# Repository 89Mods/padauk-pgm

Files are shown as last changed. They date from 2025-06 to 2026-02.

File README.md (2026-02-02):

# PMS150 programmer

Open-source programmer for the Padauk PMS150 / PMC150 devices, specifically the SOT23-5 variants (SOIC-8 not supported right now).

This programmer was designed to replicate the scope traces from reverse engineering of the official programmer as closely as possible. The only thing it can’t do is modulate the VDD voltage on the target device, but can change the VPP voltage to any level between 7V and 13V or shut it off entirely.

This project is not yet the simplest possible programmer, just a jumping off point for me to start optimizing from. Its actually quite overkill, as experimenting with the hardware already shows that a constant VPP of 11V is fine and, except for Q3, the FETs could be replaced by direct connections to GPIO pins on the CH32V003. The currents involved are way too tiny to require FETs to switch them. At some point in the future, I will make a new revision of this programmer that is truly as minimal as possible.

Included in this repo is also a primitive Verilog model of this MCU, together with a verilator testbench to help me test my code before I burn it onto a OTP device.

I also added support for PDK13 devices to my fork of the AS Assembler. [Check it out here.](https://github.com/AvalonSemiconductors/asl-avalonsemi/tree/avalonsemi)

The SPI programming interface does not reset properly unless ALL chip pins are floated! I believed that having the SPI lines and GND pin connected to ground while power is reset would be alright, but this breaks things. All must be floated.

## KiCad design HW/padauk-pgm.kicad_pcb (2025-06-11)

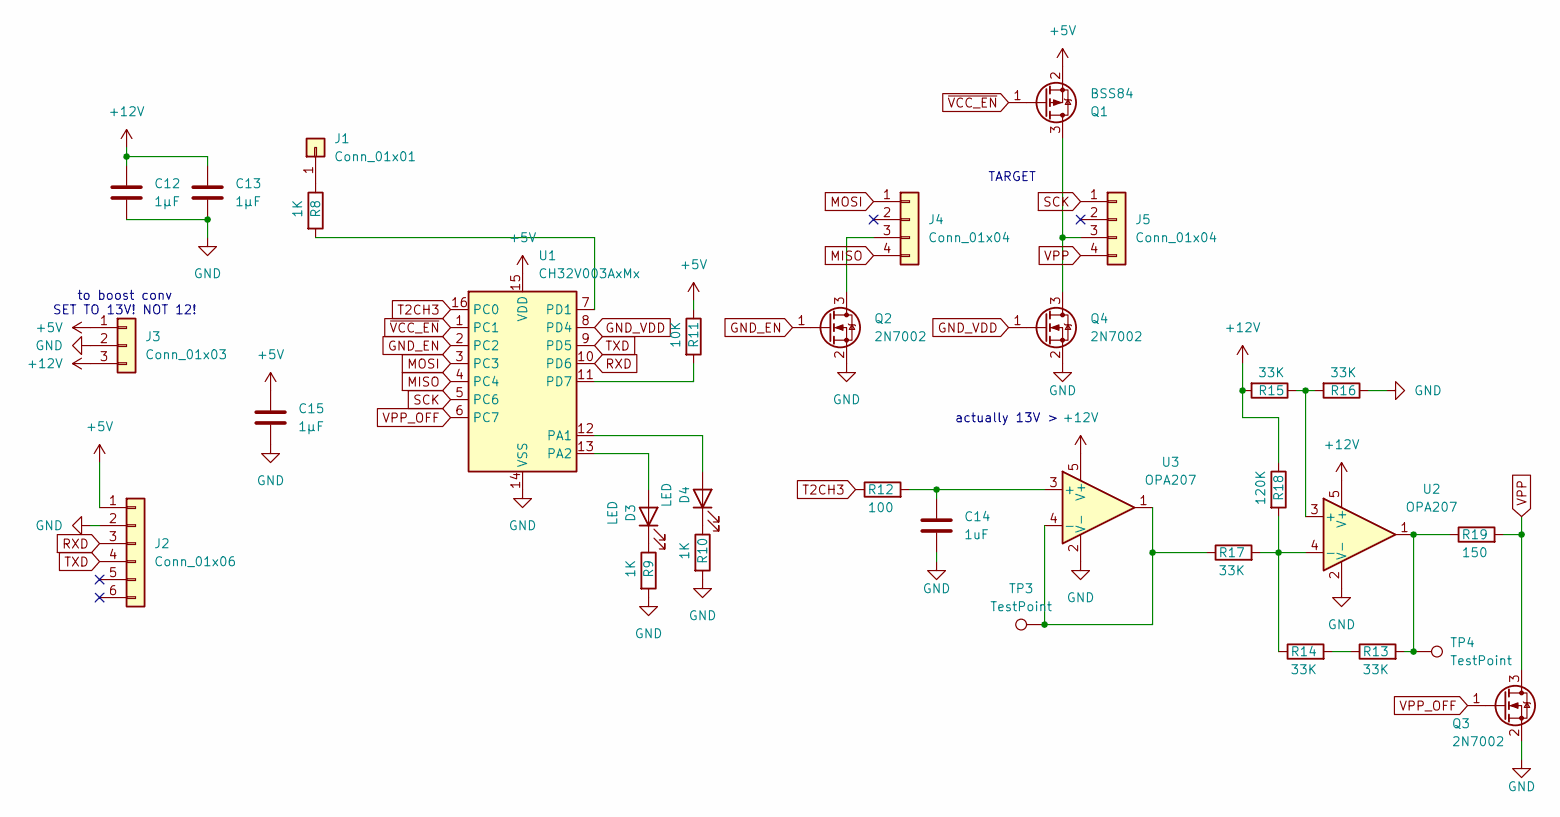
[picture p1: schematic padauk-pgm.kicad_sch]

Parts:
C12, C13, C15: 1µF; C_0805_2012Metric_Pad1.18x1.45mm_HandSolder
C14: 1uF; C_1206_3216Metric
D3, D4: LED; LED_1206_3216Metric_Pad1.42x1.75mm_HandSolder
J1: Conn_01x01; PinHeader_1x01_P2.54mm_Vertical
J2: Conn_01x06; PinSocket_1x06_P2.54mm_Vertical
J3: Conn_01x03; PinHeader_1x03_P2.54mm_Vertical
J4, J5: Conn_01x04; PinHeader_1x04_P2.54mm_Vertical
Q1: BSS84; SOT-23
Q2, Q3, Q4: 2N7002; SOT-23
R8, R9, R10: 1K; R_1206_3216Metric_Pad1.30x1.75mm_HandSolder
R11: 10K; R_1206_3216Metric_Pad1.30x1.75mm_HandSolder
R12: 100; R_1206_3216Metric_Pad1.30x1.75mm_HandSolder
R13, R14, R15, R16, R17: 33K; R_1206_3216Metric_Pad1.30x1.75mm_HandSolder
R18: 120K; R_1206_3216Metric_Pad1.30x1.75mm_HandSolder
R19: 150; R_1206_3216Metric_Pad1.30x1.75mm_HandSolder
TP3, TP4: TestPoint; TestPoint_Keystone_5019_Miniature
U1: CH32V003AxMx; SOP-16_3.9x9.9mm_P1.27mm
U2, U3: OPA207; SOT-23-5_HandSoldering

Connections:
+5V: C15.2, J2.1, J3.1, Q1.2 (S), R11.1, U1.15 (VDD)
+12V: C12.2, C13.2, J3.3, R15.2, R18.1, U2.5 (V+), U3.5 (V+)
GND: C12.1, C13.1, C14.1, C15.1, J2.2, J3.2, Q2.2 (S), Q3.2 (S), Q4.2 (S), R9.2, R10.2, R16.1, U1.14 (VSS), U2.2 (V-), U3.2 (V-)
GND_EN: Q2.1 (G), U1.2 (PC2)
GND_VDD: Q4.1 (G), U1.8 (PD4)
MISO: J4.4, U1.4 (PC4)
MOSI: J4.1, U1.3 (PC3)
unnamed: D3.2 (A), U1.13 (PA2)
unnamed: D3.1 (K), R9.1
unnamed: D4.2 (A), U1.12 (PA1)
unnamed: D4.1 (K), R10.1
unnamed: J1.1, R8.1
unnamed: J4.3, Q2.3 (D)
unnamed: J5.3, Q1.3 (D), Q4.3 (D)
unnamed: R13.1, R14.2
unnamed: R13.2, R19.1, TP4.1, U2.1
unnamed: R8.2, U1.7 (PD1)
unnamed: R11.2, U1.11 (PD7)
unnamed: R15.1, R16.2, U2.3 (+)
unnamed: R14.1, R17.2, R18.2, U2.4 (-)
unnamed: C14.2, R12.2, U3.3 (+)
unnamed: R17.1, TP3.1, U3.1, U3.4 (-)
RXD: J2.3, U1.10 (PD6)
SCK: J5.1, U1.5 (PC6)
T2CH3: R12.1, U1.16 (PC0)
TXD: J2.4, U1.9 (PD5)
VPP: J5.4, Q3.3 (D), R19.2
VPP_OFF: Q3.1 (G), U1.6 (PC7)
~VCC_EN: Q1.1 (G), U1.1 (PC1)

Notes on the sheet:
TARGET
to boost conv SET TO 13V! NOT 12!
actually 13V >

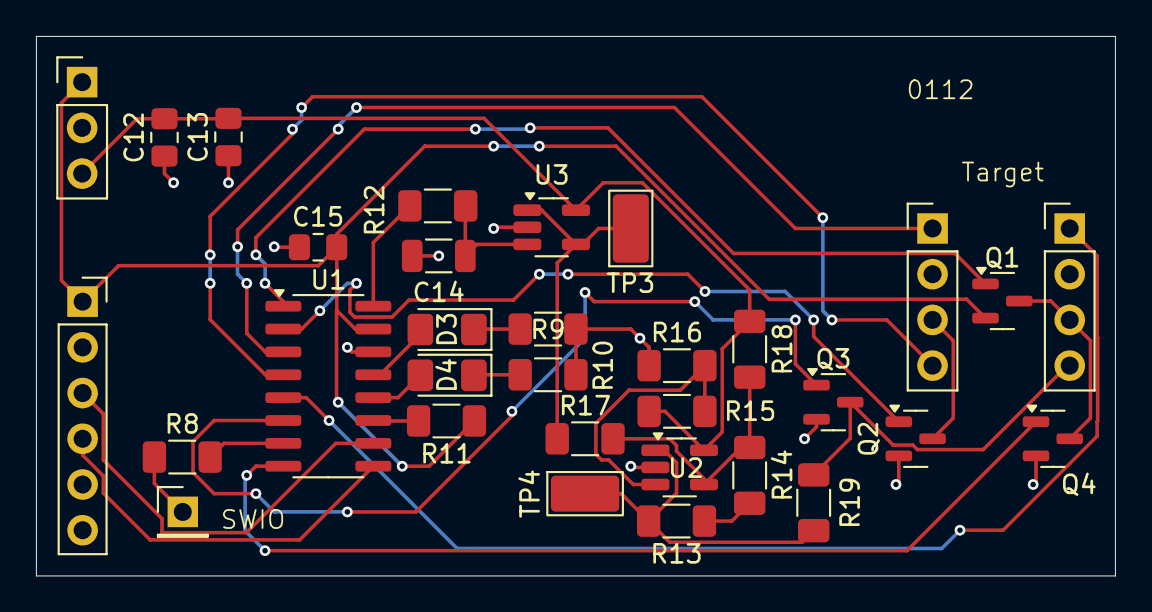
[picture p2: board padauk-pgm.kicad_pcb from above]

Board: 2 copper layers, 59.9 x 30.0 mm, 32 parts (0 on the bottom side), 29 nets.

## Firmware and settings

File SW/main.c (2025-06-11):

#include "funconfig.h"

#include <stdint.h>

#include "ch32fun.h"
#include "ch32v003_uart.h"

#include <stdio.h>

#define VCC_ENb PC1
#define GND_EN PC2
#define MOSI PC3
#define MISO PC4
#define SCK PC6
#define VPP_OFF PC7
#define GND_VDD PD4

#define LEVEL_10_8V 0x7E
#define LEVEL_7_5V 0xD4
#define LEVEL_LOWEST 0xFF

const char hexchars[] = "0123456789ABCDEF";

void newl() {
	UART_putc(13);
	UART_putc(10);
}

void puthex8(uint8_t c) {
	UART_putc(hexchars[c >> 4]);
	UART_putc(hexchars[c & 0xf]);
}

void puthex16(uint16_t c) {
	UART_putc(hexchars[c >> 12]);
	UART_putc(hexchars[(c >> 8) & 0xF]);
	UART_putc(hexchars[(c >> 4) & 0xF]);
	UART_putc(hexchars[c & 0xf]);
}

void puthex12(uint16_t c) {
	UART_putc(hexchars[(c >> 8) & 0xF]);
	UART_putc(hexchars[(c >> 4) & 0xF]);
	UART_putc(hexchars[c & 0xf]);
}

void power_target_on() {
	funDigitalWrite(PA1, FUN_HIGH);
	funDigitalWrite(GND_VDD, FUN_LOW);
	funDigitalWrite(VCC_ENb, FUN_LOW);
	funDigitalWrite(GND_EN, FUN_HIGH);
	funPinMode(MOSI, GPIO_Speed_10MHz | GPIO_CNF_OUT_PP);
	funPinMode(SCK, GPIO_Speed_10MHz | GPIO_CNF_OUT_PP);
	funDigitalWrite(MOSI, FUN_LOW);
	funDigitalWrite(SCK, FUN_LOW);
}

void float_target_power() {
	funDigitalWrite(GND_VDD, FUN_LOW);
	funDigitalWrite(VCC_ENb, FUN_HIGH);
	funPinMode(MOSI, GPIO_CFGLR_IN_FLOAT);
	funPinMode(SCK, GPIO_CFGLR_IN_FLOAT);
	funDigitalWrite(GND_EN, FUN_LOW);
	funPinMode(MOSI, GPIO_Speed_10MHz | GPIO_CNF_OUT_PP);
	funDigitalWrite(MOSI, FUN_LOW);
	funPinMode(SCK, GPIO_Speed_10MHz | GPIO_CNF_OUT_PP);
	funDigitalWrite(SCK, FUN_LOW);
	Delay_Us(3);
}

void power_target_off() {
	funDigitalWrite(PA1, FUN_LOW);
	TIM2->CH3CVR = LEVEL_LOWEST;
	funDigitalWrite(VPP_OFF, FUN_HIGH);
	Delay_Us(2);
	funDigitalWrite(VCC_ENb, FUN_HIGH);
	funDigitalWrite(GND_EN, FUN_HIGH);
	funDigitalWrite(GND_VDD, FUN_HIGH);
	funDigitalWrite(MOSI, FUN_LOW);
	funDigitalWrite(SCK, FUN_LOW);
	funPinMode(MOSI, GPIO_CFGLR_IN_FLOAT);
	funPinMode(SCK, GPIO_CFGLR_IN_FLOAT);
	Delay_Ms(1);
}

#define SPI_DEL 5

uint8_t spi_tfr(uint8_t val) {
	uint8_t res = 0;
	for(uint8_t i = 0; i < 8; i++) {
		if((val & 128) != 0) {funDigitalWrite(MOSI, FUN_HIGH);}
		else {funDigitalWrite(MOSI, FUN_LOW);}
		Delay_Us(SPI_DEL);
		val <<= 1;
		res <<= 1;
		if(funDigitalRead(MISO)) res |= 1;
		funDigitalWrite(SCK, FUN_HIGH);
		Delay_Us(SPI_DEL);
		funDigitalWrite(SCK, FUN_LOW);
		Delay_Us(SPI_DEL);
	}
	Delay_Us(SPI_DEL);
	return res;
}

uint16_t spi_tx13(uint16_t val) {
	uint16_t res = 0;
	for(uint8_t i = 0; i < 13; i++) {
		if((val & 4096) != 0) {funDigitalWrite(MOSI, FUN_HIGH);}
		else {funDigitalWrite(MOSI, FUN_LOW);}
		res <<= 1;
		val <<= 1;
		Delay_Us(SPI_DEL);
		if(funDigitalRead(MISO)) res |= 1;
		funDigitalWrite(SCK, FUN_HIGH);
		Delay_Us(SPI_DEL);
		funDigitalWrite(SCK, FUN_LOW);
		Delay_Us(SPI_DEL);
	}
	Delay_Us(SPI_DEL);
	return res;
}

uint16_t spi_tx12(uint16_t val) {
	uint16_t res = 0;
	for(uint8_t i = 0; i < 12; i++) {
		if((val & 2048) != 0) {funDigitalWrite(MOSI, FUN_HIGH);}
		else {funDigitalWrite(MOSI, FUN_LOW);}
		val <<= 1;
		res <<= 1;
		Delay_Us(SPI_DEL);
		if(funDigitalRead(MISO)) res |= 1;
		funDigitalWrite(SCK, FUN_HIGH);
		Delay_Us(SPI_DEL);
		funDigitalWrite(SCK, FUN_LOW);
		Delay_Us(SPI_DEL);
	}
	Delay_Us(SPI_DEL);
	return res;
}

void key_sequence(uint8_t write) {
	TIM2->CH3CVR = LEVEL_7_5V;
	float_target_power();
	funDigitalWrite(VPP_OFF, FUN_LOW);
	Delay_Us(100);
	power_target_on();
	Delay_Us(500);
	spi_tfr(0xA5); spi_tfr(0xA5); spi_tfr(0xA5); Delay_Us(1);
	spi_tfr(write ? 0xA7 : 0xA6);
	Delay_Us(10);
	if(write) {
		TIM2->CH3CVR = LEVEL_10_8V;
		Delay_Ms(15);
	}
}

uint8_t check_id(void) {
	key_sequence(1);
	spi_tx13(0x0000); spi_tx13(0x0000);
	uint16_t device_id = 0;
	device_id = spi_tx12(0x000);
	power_target_off();
	Delay_Ms(50);
	if(device_id != 0xA16) {
		UART_printf("Invalid device ID %x\r\n", device_id);
		return 1;
	}
	return 0;
}

uint8_t UART_waitForChar(void) {
	uint16_t i;
	while(1) {
		i = UART_getc();
		if(i == UART_NO_DATA) continue;
		if((i & 0xFF00) != 0) return 0;
		return i & 0xFF;
	}
}

#define CHIP_SIZE 1024
#define CHIP_SIZE_PROGRAMMABLE (1024-16)

uint8_t doDump(void) {
	if(check_id()) return 1;
	key_sequence(0);
	for(uint16_t i = 0; i < CHIP_SIZE; i++) {
		spi_tx12(i);
		funDigitalWrite(SCK, FUN_HIGH);
		uint16_t val = spi_tx13(0);
		if((i & 15) == 0) {
			UART_putc(13);
			UART_putc(10);
			puthex12(i);
		}
		UART_putc(' ');
		puthex16(val);
	}
	UART_putc(13);
	UART_putc(10);
	power_target_off();
	Delay_Ms(50);
	return 0;
}

uint8_t doProgramming(void) {
	if(check_id()) return 2;
	key_sequence(0);
	for(uint16_t i = 0; i < CHIP_SIZE_PROGRAMMABLE; i++) {
		spi_tx12(i);
		funDigitalWrite(SCK, FUN_HIGH);
		uint16_t val = spi_tx13(0);
		if(val != 0x1FFF) {
			power_target_off();
			Delay_Ms(50);
			UART_printf("Chip not blank, programmed word found at address 0x%x\r\n", i);
			return 1;
		}
	}
	power_target_off();
	Delay_Ms(50);
	UART_putc('a');
	uint32_t len = UART_waitForChar() - 'A';
	len |= (uint16_t)(UART_waitForChar() - 'A') << 4;
	len |= (uint16_t)(UART_waitForChar() - 'A') << 8;
	len |= (uint16_t)(UART_waitForChar() - 'A') << 12;
	if(len > CHIP_SIZE_PROGRAMMABLE) {
		UART_printf("THAT’S TOO BIG!\r\n");
		return 1;
	}
	if((len & 1) != 0) {
		UART_printf("Uneven size not permitted\r\n");
		return 1;
	}
	uint8_t uneven = len & 3;
	uint32_t end = len >> 2;
	if(uneven) end++;
	key_sequence(1);
	for(uint32_t i = 0; i < end; i++) {
		UART_putc('n');
		uint16_t val = UART_waitForChar();
		UART_putc('n');
		val |= (uint16_t)UART_waitForChar() << 8;
		uint16_t val2 = 0x1FFF;
		if(!(i == end - 1 && uneven)) {
			UART_putc('n');
			val2 = UART_waitForChar();
			UART_putc('n');
			val2 |= (uint16_t)UART_waitForChar() << 8;
		}
		spi_tx13(val);
		spi_tx13(val2);
		spi_tx12(i << 1);
		//Send 0 bit to initiate write
		funDigitalWrite(MOSI, FUN_LOW);
		Delay_Us(SPI_DEL);
		funDigitalWrite(SCK, FUN_HIGH);
		Delay_Us(SPI_DEL);
		funDigitalWrite(SCK, FUN_LOW);
		Delay_Us(SPI_DEL);
		funDigitalWrite(SCK, FUN_HIGH);
		Delay_Us(SPI_DEL * 2);
		for(uint8_t j = 0; j < 8; j++) {
			funDigitalWrite(MOSI, FUN_HIGH);
			Delay_Us(61);
			funDigitalWrite(MOSI, FUN_LOW);
			Delay_Us(61);
		}
		Delay_Us(SPI_DEL);
		funDigitalWrite(SCK, FUN_LOW);
		//Trailing 0 bit to end write
		Delay_Us(SPI_DEL);
		funDigitalWrite(SCK, FUN_HIGH);
		Delay_Us(SPI_DEL);
		funDigitalWrite(SCK, FUN_LOW);
		Delay_Us(SPI_DEL);
	}
	power_target_off();
	UART_putc('d');
	key_sequence(0);
	for(uint32_t i = 0; i < end; i++) {
		UART_waitForChar();
		spi_tx12(i << 1);
		funDigitalWrite(SCK, FUN_HIGH);
		uint16_t val = spi_tx13(0);
		UART_putc((val & 15) + 48);
		UART_putc(((val >> 4) & 15) + 48);
		UART_waitForChar();
		val >>= 8;
		UART_putc((val & 15) + 48);
		UART_putc(((val >> 4) & 15) + 48);
		if(!(i == end - 1 && uneven)) {
			UART_waitForChar();
			spi_tx12((i << 1) | 1);
			funDigitalWrite(SCK, FUN_HIGH);
			val = spi_tx13(0);
			UART_putc((val & 15) + 48);
			UART_putc(((val >> 4) & 15) + 48);
			UART_waitForChar();
			val >>= 8;
			UART_putc((val & 15) + 48);
			UART_putc(((val >> 4) & 15) + 48);
		}
	}
	power_target_off();
	return 0;
}

int main() {
	SystemInit();
	AFIO->PCFR1 &= ~(1 << 15);
	RCC->CTLR &= ~(1 << 16);
	funGpioInitAll();
	UART_init();
	funPinMode( PC0,     GPIO_Speed_10MHz | GPIO_CNF_OUT_PP_AF );
	funPinMode( PD5,     GPIO_Speed_10MHz | GPIO_CNF_OUT_PP_AF );
	
	RCC->APB1PCENR |= RCC_APB1Periph_TIM2;
	RCC->APB1PRSTR |= RCC_APB1Periph_TIM2;
	RCC->APB1PRSTR &= ~RCC_APB1Periph_TIM2;
	TIM2->PSC = 0x0000;
	TIM2->ATRLR = 255;
	TIM2->CHCTLR2 |= TIM_OC3M_2 | TIM_OC3M_1 | TIM_OC3PE;
	TIM2->CTLR1 |= TIM_ARPE;
	TIM2->CCER |= TIM_CC3E | (TIM_CC3P & 0xff);
	TIM2->SWEVGR |= TIM_UG;
	TIM2->CTLR1 |= TIM_CEN;
	TIM2->CH3CVR = LEVEL_LOWEST;
	
	funPinMode(VCC_ENb, GPIO_Speed_10MHz | GPIO_CNF_OUT_PP);
	funDigitalWrite(VCC_ENb, FUN_HIGH);
	funPinMode(GND_EN, GPIO_Speed_10MHz | GPIO_CNF_OUT_PP);
	funDigitalWrite(GND_EN, FUN_HIGH);
	funPinMode(MOSI, GPIO_CFGLR_IN_FLOAT);
	funPinMode(SCK, GPIO_CFGLR_IN_FLOAT);
	
	funPinMode(MISO, GPIO_CFGLR_IN_PUPD);
	funPinMode(VPP_OFF, GPIO_Speed_10MHz | GPIO_CNF_OUT_PP);
	funDigitalWrite(VPP_OFF, FUN_HIGH);
	funPinMode(GND_VDD, GPIO_Speed_10MHz | GPIO_CNF_OUT_PP);
	funDigitalWrite(GND_VDD, FUN_HIGH);
	
	funPinMode(PA2, GPIO_Speed_10MHz | GPIO_CNF_OUT_PP);
	funDigitalWrite(PA2, FUN_HIGH);
	funPinMode(PA1, GPIO_Speed_10MHz | GPIO_CNF_OUT_PP);
	funDigitalWrite(PA1, FUN_LOW);
	
	while(1) {
		power_target_off();
		UART_printf("\r\nPress 9 to continue\r\n");
		Delay_Ms(50);
		uint8_t mode = 0;
		while(1) {
			mode = UART_getc();
			if(mode == '9') break;
			Delay_Ms(1);
		}
		UART_printf("Press r to dump ROM\r\n");
		while(1) {
			mode = UART_getc();
			if(mode == 'r') {
				doDump();
				break;
			}
			if(mode == 'p') {
				doProgramming();
				break;
			}
			Delay_Ms(1);
		}
		
		Delay_Ms(509);
	}
}

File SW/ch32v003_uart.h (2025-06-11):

#ifndef _CH32V003_UART_H
#define _CH32V003_UART_H
/**
 * @file ch32v003_uart.h
 * @author Piotr Zapart
 * @brief CH32V003 generic UART library, 8N1, default 115200baud, No parity, no flow control
 * @version 0.1
 * @date 2023-07-22
 * 
 *  Caution! 
 *  ============================================================
 *  Library will not work if FUNCONF_USE_UARTPRINTF is defined!
 *  ============================================================
 * 
 *	USART1 mapping configuration high (used in conjunction with AFIO PCFR1 register bit2
 *	USART1RM [21,2]).
 * 	00: default mapping (CK/PD4, TX/PD5, RX/PD6, CTS/PD3, RTS/PC2, SW_RX/PD5).
 *	01: Remapping (CK/PD7, TX/PD0, RX/PD1, CTS/PC3, RTS/PC2, SW_RX/PD0).
 *	10: Remapping (CK/PD7, TX/PD6, RX/PD5, CTS/PC6, RTS/PC7, SW_RX/PD6).
 *	11: Remapping (CK/PC5, TX/PC0, RX/PC1, CTS/PC6, RTS/PC7, SW_RX/PC0).
 *
 * Usage:
 * 1. In funconfig.h define the baudrate:
 *    #define FUNCONF_UART_PRINTF_BAUD 115200 //used for uart library
 * 
 * 2. In main source file: optionally define the TXRX pin configuration. If not defined
 *    the standard TX=PD5, RX=PD6 is used, alternative settings:
 *    #define UART_PINS_TXPD0_RXPD1 or
 *    #define UART_PINS_TXPC0_RXPC1 or
 *    #define UART_PINS_TXPD6_RXPD5 - this is the TXRX swap setting
 * 
 * 3. X or RX can be disabled separately, for TX only UART add the following define
 *    #define UART_MODE_TX
 *    for RX only: #define UART_MODE_RX
 *    Default setting is both, TX and RX enabled
 * 	
 * 4. In main source file add
 *    #define CH32V003_UART_IMPLEMENTATION
 * 5. Then include the header file
 *    #include "ch32v003_uart.h"
 * 
 * 	To send a byte:
 * 		UART_putc(dataByte);
 * 	To print something:
 * 		UART_printf(...)
 *  To receive a byte:
 * 		uint16 in = UART_getc();
 * 	The higher byte contains error flags, function returns UART_NO_DATA if all has been 
 *  read from the receive buffer.
 *  	if( in != UART_NO_DATA )
 * 				receivedByte = in & 0xFF;
 * 
 *  TX and RX buffer sizes are set to 32 bytes. Both values have to be power of 2! 
 */
#include <stdarg.h>
#include <string.h>
#include "ch32fun.h"
// use uart only if debug printf is enables
#if defined( FUNCONF_USE_DEBUGPRINTF ) && FUNCONF_USE_DEBUGPRINTF

#define UART_TX_BF_SIZE	256	// tx buffer size, has to be power of 2!
#define UART_RX_BF_SIZE	256	// rx buffer size, has to be power of 2!

#define UART_TX_BF_MASK	(UART_TX_BF_SIZE-1)
#define UART_RX_BF_MASK	(UART_RX_BF_SIZE-1)

#if ( UART_TX_BF_SIZE & UART_TX_BF_MASK )
#error TX buffer size is not a power of 2
#endif
#if ( UART_RX_BF_MASK & UART_RX_BF_SIZE )
#error RX buffer size is not a power of 2
#endif

#define UART_IT_ERROR_MASK			(0x0E)		// FE + NE + ORE
#define UART_ERR_CHKSUM				(0x0100)	// Checksum error flag	| USART1_STATR << 8
#define UART_ERR_FRAME     			(0x0200)	// Frame error flag		|
#define UART_ERR_NOISE				(0x0400)	// Noise error flag		| 
#define UART_ERR_OVERRUN 		    (0x0800)	// Overload error flag	|
#define UART_ERR_RXBUF_OVERFLOW 	(0x0100)	// RX buffer overflow
#define UART_NO_DATA          		(0x8000) 	// No data received

#define UART_AFIO_PCFR1_RESET_MASK	(0xFFDFFFFB)	// bit 2 & bit 21 

#if defined(UART_PINS_TXPD0_RXPD1)
	#define UART_PORT_RCC	RCC_APB2Periph_GPIOD
	#define UART_PORT		GPIOD 
	#define UART_PIN_TX 	0
	#define UART_PIN_RX 	1
	#define UART_AFIO_PCFR1	(1<<2)							//remap 01
#elif defined (UART_PINS_TXPC0_RXPC1)
	#define UART_PORT_RCC	RCC_APB2Periph_GPIOC
	#define UART_PORT		GPIOC
	#define UART_PIN_TX 	0
	#define UART_PIN_RX 	1
	#define UART_AFIO_PCFR1	((1<<21)|(1<<2))				//remap 11
#elif defined (UART_PINS_TXPD6_RXPD5)
	#define UART_PORT_RCC	RCC_APB2Periph_GPIOD
	#define UART_PORT		GPIOD 
	#define UART_PIN_TX 	6
	#define UART_PIN_RX 	5
	#define UART_AFIO_PCFR1	(1<<21)							// remap 10
#else 
	#define UART_PINS_TXPD5_RXPD6
	#define UART_PORT_RCC	RCC_APB2Periph_GPIOD
	#define UART_PORT		GPIOD 
	#define UART_PIN_TX 	5
	#define UART_PIN_RX 	6
	#define UART_AFIO_PCFR1	(0)	//default 00
#endif
// if no config is provided, use tx+rx as default
#if !defined(UART_MODE_TX) && !defined(UART_MODE_RX) && !defined(UART_MODE_TXRX)
	#define UART_MODE_TXRX
#endif	

#if defined (UART_MODE_TXRX)
	#define UART_MODE_TX
	#define UART_MODE_RX
#endif

void UART_init();			// baudrate set in funconf.h using FUNCONF_UART_PRINTF_BAUD

#if defined(CH32V003_UART_IMPLEMENTATION)

#if defined(UART_MODE_TX)
	#define UART_IT_TXE_ENABLE		(0x0080)
	#define UART_IT_TXE_DISABLE		(0xFF7F)
	uint8_t uart_tx_bf[UART_TX_BF_SIZE]; // transmit buffer
	static volatile uint8_t uart_txHead, uart_txTail;
	static volatile uint16_t lastTXerrorFlag = 0;
	void UART_putc(uint8_t data);
	int UART_write(const char *buf, int size);
	static int UART_puts(char *s, int len, void *buf);
	int UART_printf(const char* format, ...);		
	int mini_vpprintf(int (*puts)(char* s, int len, void* buf), void* buf, const char *fmt, va_list va);
#endif

#if defined (UART_MODE_RX)
	#define UART_IT_RXC_ENABLE		(0x0020)
	#define UART_IT_RXC_DISABLE		(0xFFDF)
	uint8_t uart_rx_bf[UART_TX_BF_SIZE]; // transmit buffer	
	static volatile uint8_t uart_rxHead, uart_rxTail;
	static volatile uint16_t lastRXerrorFlag = 0;
	uint16_t UART_getc(void);
#endif
// --------------------------------------------------------
/**
 * @brief Initialoze USART1 with predefined settings
 */
void UART_init()
{
	uint16_t tmp16 = USART_WordLength_8b | USART_Parity_No;
	RCC->APB2PCENR |= UART_PORT_RCC | RCC_APB2Periph_USART1 | RCC_APB2Periph_AFIO;

	AFIO->PCFR1 &= UART_AFIO_PCFR1_RESET_MASK;
	AFIO->PCFR1 |= UART_AFIO_PCFR1;

#if defined(UART_MODE_TX)
	UART_PORT->CFGLR &= ~(0xf<<(4*UART_PIN_TX));
	UART_PORT->CFGLR |= (GPIO_Speed_10MHz | GPIO_CNF_OUT_PP_AF)<<(4*UART_PIN_TX);
	tmp16 |= USART_Mode_Tx;
	uart_txHead = 0;
	uart_txTail = 0;
#endif
#if defined (UART_MODE_RX)
	UART_PORT->CFGLR &= ~(0xf<<(4*UART_PIN_RX));
	UART_PORT->CFGLR |= (GPIO_Speed_10MHz | GPIO_CNF_IN_PUPD)<<(4*UART_PIN_RX);
	tmp16 |= USART_Mode_Rx | UART_IT_RXC_ENABLE;	// enable TX and rx complete interrupt
	uart_rxHead = 0;
	uart_rxTail = 0;	
#endif
	NVIC_EnableIRQ(USART1_IRQn);
	USART1->CTLR1 =  tmp16;
	USART1->CTLR2 = USART_StopBits_1;
	USART1->CTLR3 = USART_HardwareFlowControl_None;
	USART1->BRR = UART_BRR;
	USART1->CTLR1 |= CTLR1_UE_Set;	
}
// --------------------------------------------------------
#if defined (UART_MODE_RX)
/**
 * @brief  return byte from ringbuffer  
 * 
 * @return uint16_t l	lower byte:  received byte from ringbuffer
          				higher byte: last receive error
 */
uint16_t UART_getc(void)
{    
    uint8_t tmp8, data;

    if ( uart_rxHead == uart_rxTail ) return UART_NO_DATA;

    tmp8 = (uart_rxTail + 1) & UART_RX_BF_MASK;
    uart_rxTail = tmp8; 
    
    data = uart_rx_bf[tmp8];
    
    return (lastRXerrorFlag | data);
}
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
